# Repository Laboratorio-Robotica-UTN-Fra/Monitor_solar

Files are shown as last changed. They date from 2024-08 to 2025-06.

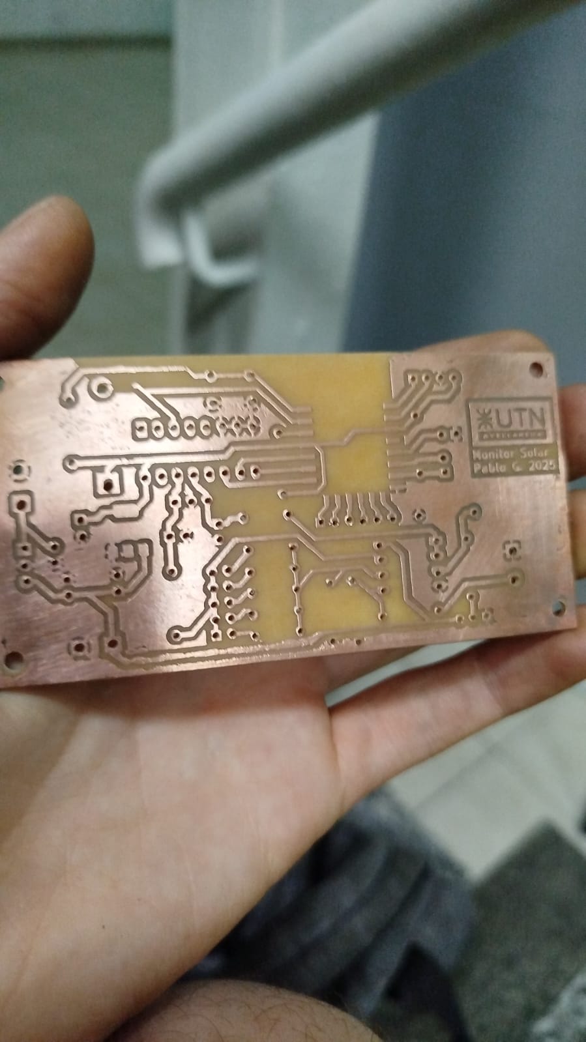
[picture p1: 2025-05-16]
img/1_placa_virgen.jpg

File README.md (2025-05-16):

# Monitor Solar

Proyecto para mostrar los valores de tension y corriente de un sistema solar

## Folder Structure

- `code/` - Archivos de codigo para esp8266.
- `Componentes/` - Documentacion y archivos de simbolos para kicad.
- `img/` - Imagenes del proyecto
- `README.md` - Explicacion del proyecto.

## Getting Started

1. Clone the repository:
    ```bash
    git clone https://github.com/yourusername/Monitor_solar.git
    ```
2. Follow instructions in `docs/` to set up and run the project.

## License

See `LICENSE` for details.

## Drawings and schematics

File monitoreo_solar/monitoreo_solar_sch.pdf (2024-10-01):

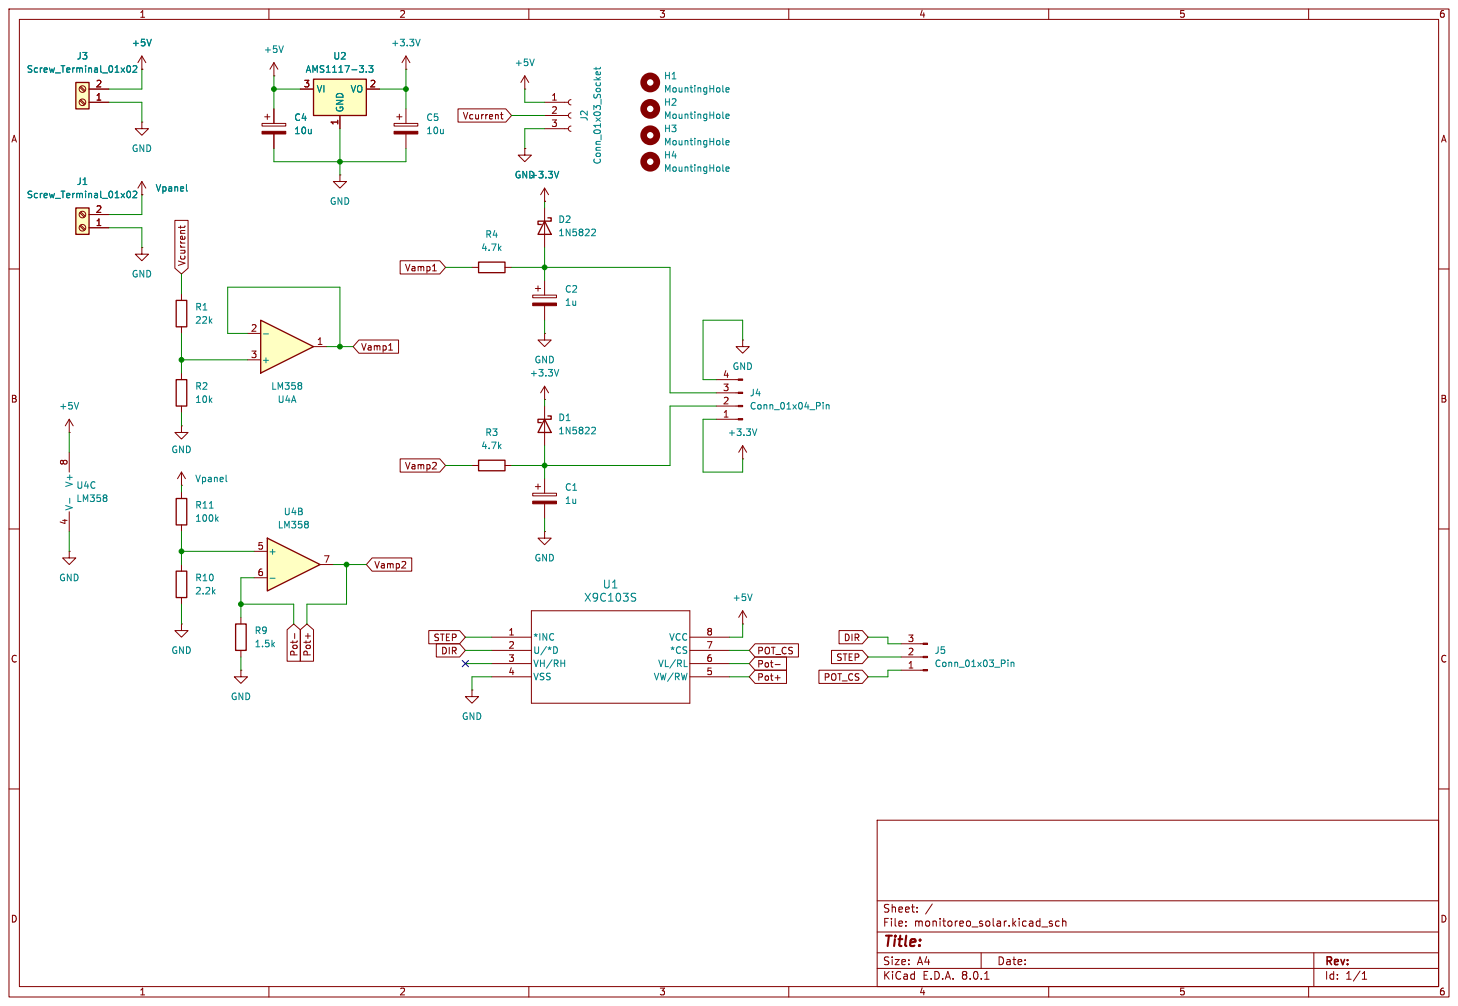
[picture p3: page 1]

Id: 1/1 Title: File: monitoreo_solar.kicad_sch Sheet: / GND

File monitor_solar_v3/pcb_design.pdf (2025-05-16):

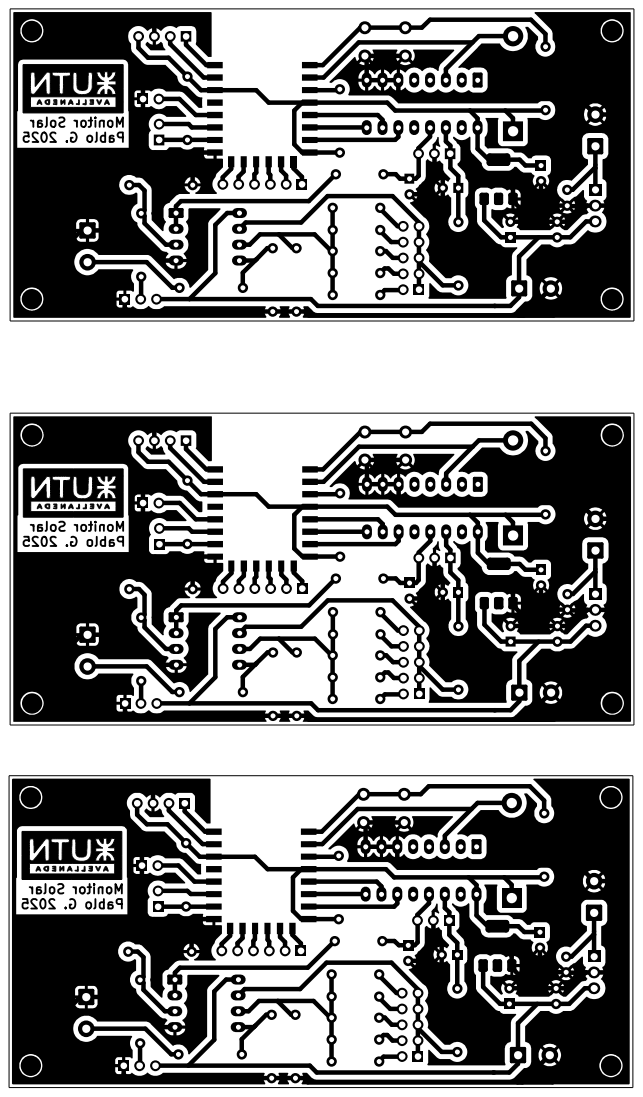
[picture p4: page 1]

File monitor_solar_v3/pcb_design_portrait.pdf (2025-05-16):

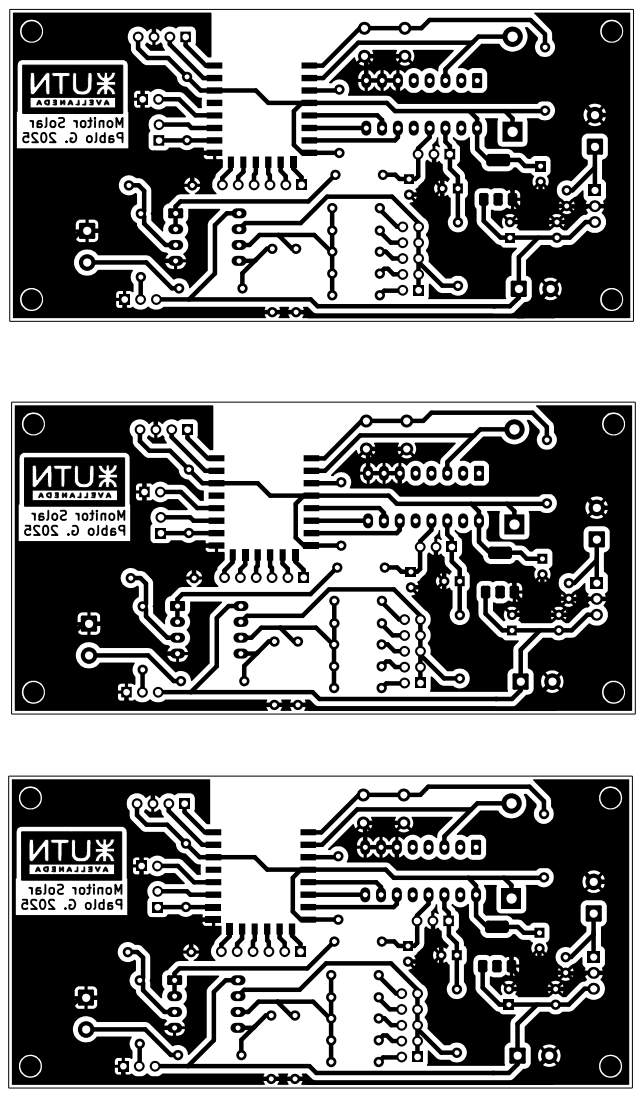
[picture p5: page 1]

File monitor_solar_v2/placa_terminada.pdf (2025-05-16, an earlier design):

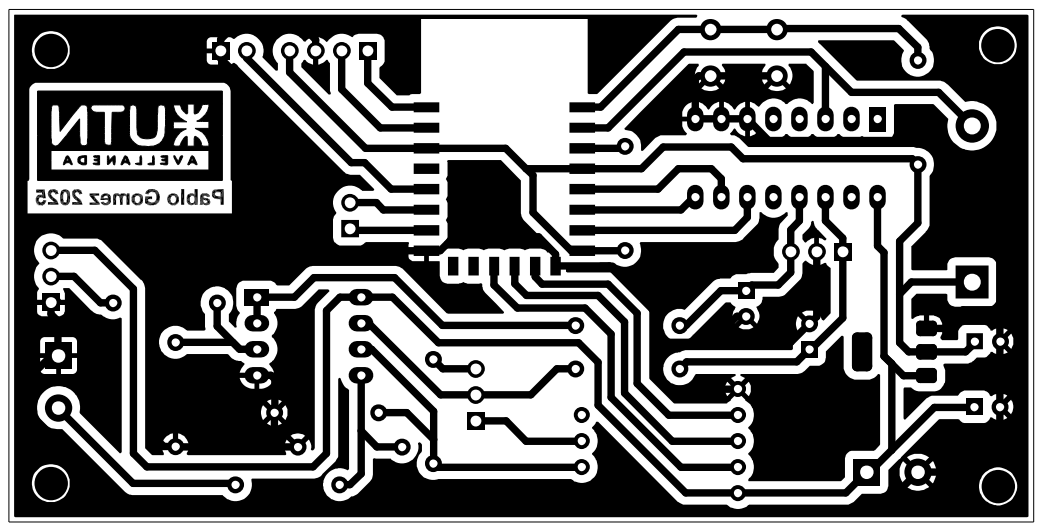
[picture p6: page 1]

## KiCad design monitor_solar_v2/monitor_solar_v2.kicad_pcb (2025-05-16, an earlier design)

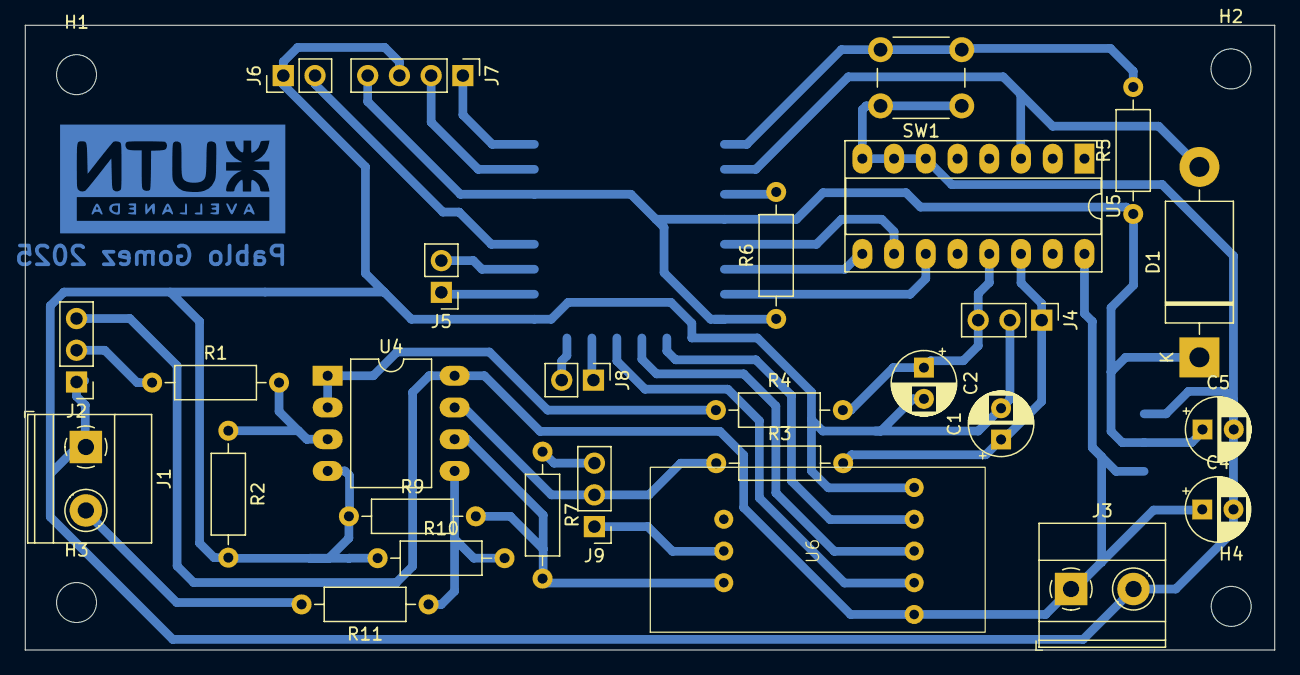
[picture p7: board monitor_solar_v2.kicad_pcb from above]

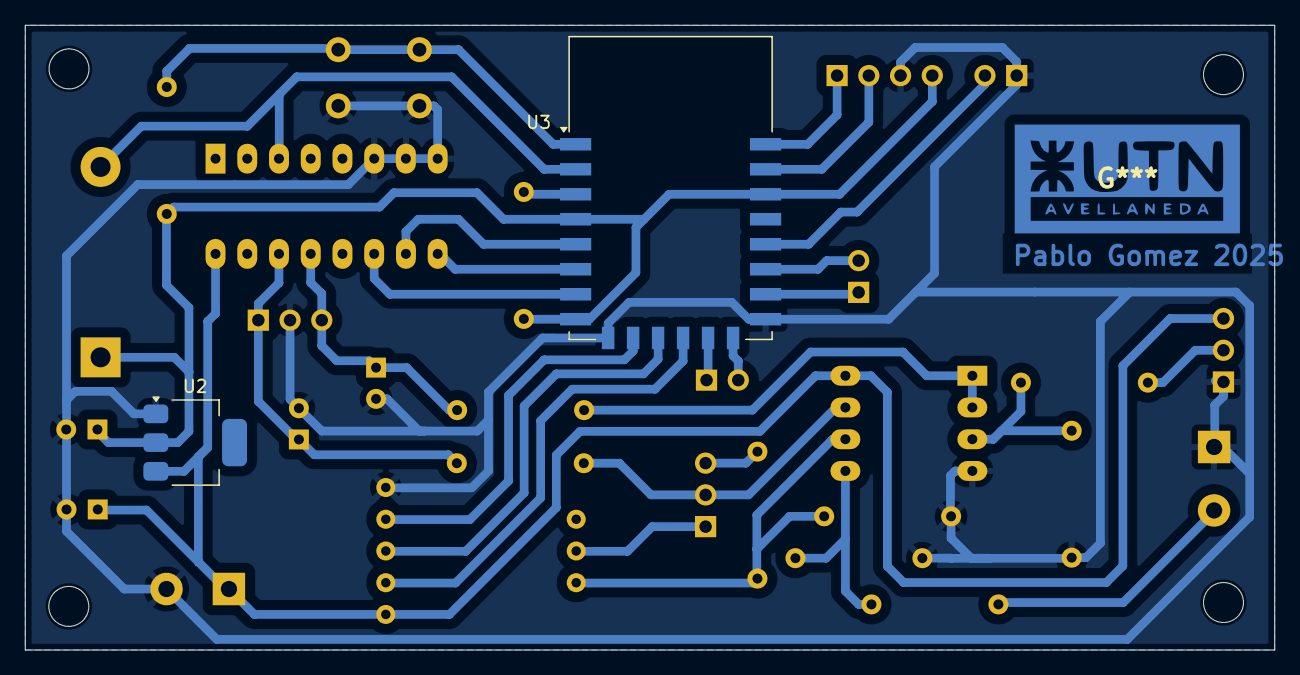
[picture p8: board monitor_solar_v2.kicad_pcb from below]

Board: 2 copper layers, 100.0 x 50.0 mm, 34 parts (2 on the bottom side), 30 nets.

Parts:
C1, C2: 1u; CP_Radial_D5.0mm_P2.50mm
C4, C5: 10u; CP_Radial_D5.0mm_P2.50mm
D1: 1N5822; D_DO-201AD_P15.24mm_Horizontal
H1, H2, H3, H4: MountingHole; MountingHole_3.2mm_M3
J1: Panel; TerminalBlock_Phoenix_MKDS-1,5-2-5.08_1x02_P5.08mm_Horizont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
J2: ACS712; PinHeader_1x03_P2.54mm_Vertical
J3: Reg 5V; TerminalBlock_Phoenix_MKDS-1,5-2_1x02_P5.00mm_Horizontal
J4: AMP_OUT; PinHeader_1x03_P2.54mm_Vertical
J5, J6: JUMPER_PROG; PinHeader_1x02_P2.54mm_Vertical
J7: PROGRAM; PinHeader_1x04_P2.54mm_Vertical
J8: GPIO_2; PinHeader_1x02_P2.54mm_Vertical
J9: Jumper_fixed_r; PinHeader_1x03_P2.54mm_Vertical
R1: 20k; R_Axial_DIN0207_L6.3mm_D2.5mm_P10.16mm_Horizontal
R2, R5, R6: 10k; R_Axial_DIN0207_L6.3mm_D2.5mm_P10.16mm_Horizontal
R3, R4: 4.7k; R_Axial_DIN0207_L6.3mm_D2.5mm_P10.16mm_Horizontal
R7: 3.3k; R_Axial_DIN0207_L6.3mm_D2.5mm_P10.16mm_Horizontal
R9: 1.5k; R_Axial_DIN0207_L6.3mm_D2.5mm_P10.16mm_Horizontal
R10: 2.2k; R_Axial_DIN0207_L6.3mm_D2.5mm_P10.16mm_Horizontal
R11: 100k; R_Axial_DIN0207_L6.3mm_D2.5mm_P10.16mm_Horizontal
SW1: SW_Push; SW_PUSH_6mm
U2: AMS1117-3.3; SOT-223-3_TabPin2
U3: ESP-12F; ESP-12E
U4: LM358; DIP-8_W10.16mm_LongPads
U5: 4051; DIP-16_W7.62mm_Socket_LongPads
U6: X9C103S

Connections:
+3.3V: C5.1, D1.1 (K), J7.4, R5.1, R6.1, U2.2 (VO), U3.4 (GPIO16), U3.8 (VCC), U3.20 (GPIO5)
+5V: C4.1, J2.3, J3.1, U2.3 (VI), U4.8 (V+), U5.16 (VDD), U6.8 (VCC)
ADC_IN: D1.2 (A), U3.2 (ADC), U5.3 (X)
DIR: U3.10 (MISO), U6.2 (U/*D)
GND: C1.2, C2.2, C4.2, C5.2, J1.1, J2.1, J3.2, J4.2, J6.1, J7.3, R2.2, R9.1, R10.1, SW1.1, U2.1 (GND), U3.9 (CS0), U3.15 (GND), U4.4 (V-), U5.6 (Inh), U5.7 (VEE), U5.8 (VSS), U6.4 (VSS)
GPIO2: J5.2, U3.17 (GPIO2)
GPIO15: J5.1, U3.16 (GPIO15)
MUX_A: U3.7 (GPIO13), U5.11 (A)
MUX_B: U3.5 (GPIO14), U5.10 (B)
MUX_C: U3.6 (GPIO12), U5.9 (C)
unnamed: J6.2, U3.18 (GPIO0)
unnamed: J8.1, U3.13 (MOSI)
unnamed: J8.2, U3.14 (SCLK)
unnamed: J9.2, R3.1, U4.7
unnamed: J9.3, R7.1
unnamed: R6.2, U3.3 (EN)
unnamed: R5.2, SW1.2, U3.1 (~RST)
unnamed: R1.2, R2.1, U4.3 (+)
unnamed: R4.1, U4.1, U4.2 (-)
unnamed: R10.2, R11.1, U4.5 (+)
POT_CS: U3.12 (GPIO10), U6.7 (*CS)
Pot+: J9.1, U6.5 (VW/RW)
Pot-: R7.2, R9.2, U4.6 (-), U6.6 (VL/RL)
RX: J7.2, U3.21 (GPIO3/RXD)
STEP: U3.11 (GPIO9), U6.1 (*INC)
TX: J7.1, U3.22 (GPIO1/TXD)
Vamp1: C2.1, J4.3, R4.2, U5.13 (X0)
Vamp2: C1.1, J4.1, R3.2, U5.14 (X1)
Vcurrent: J2.2, R1.1
Vpanel: J1.2, R11.2

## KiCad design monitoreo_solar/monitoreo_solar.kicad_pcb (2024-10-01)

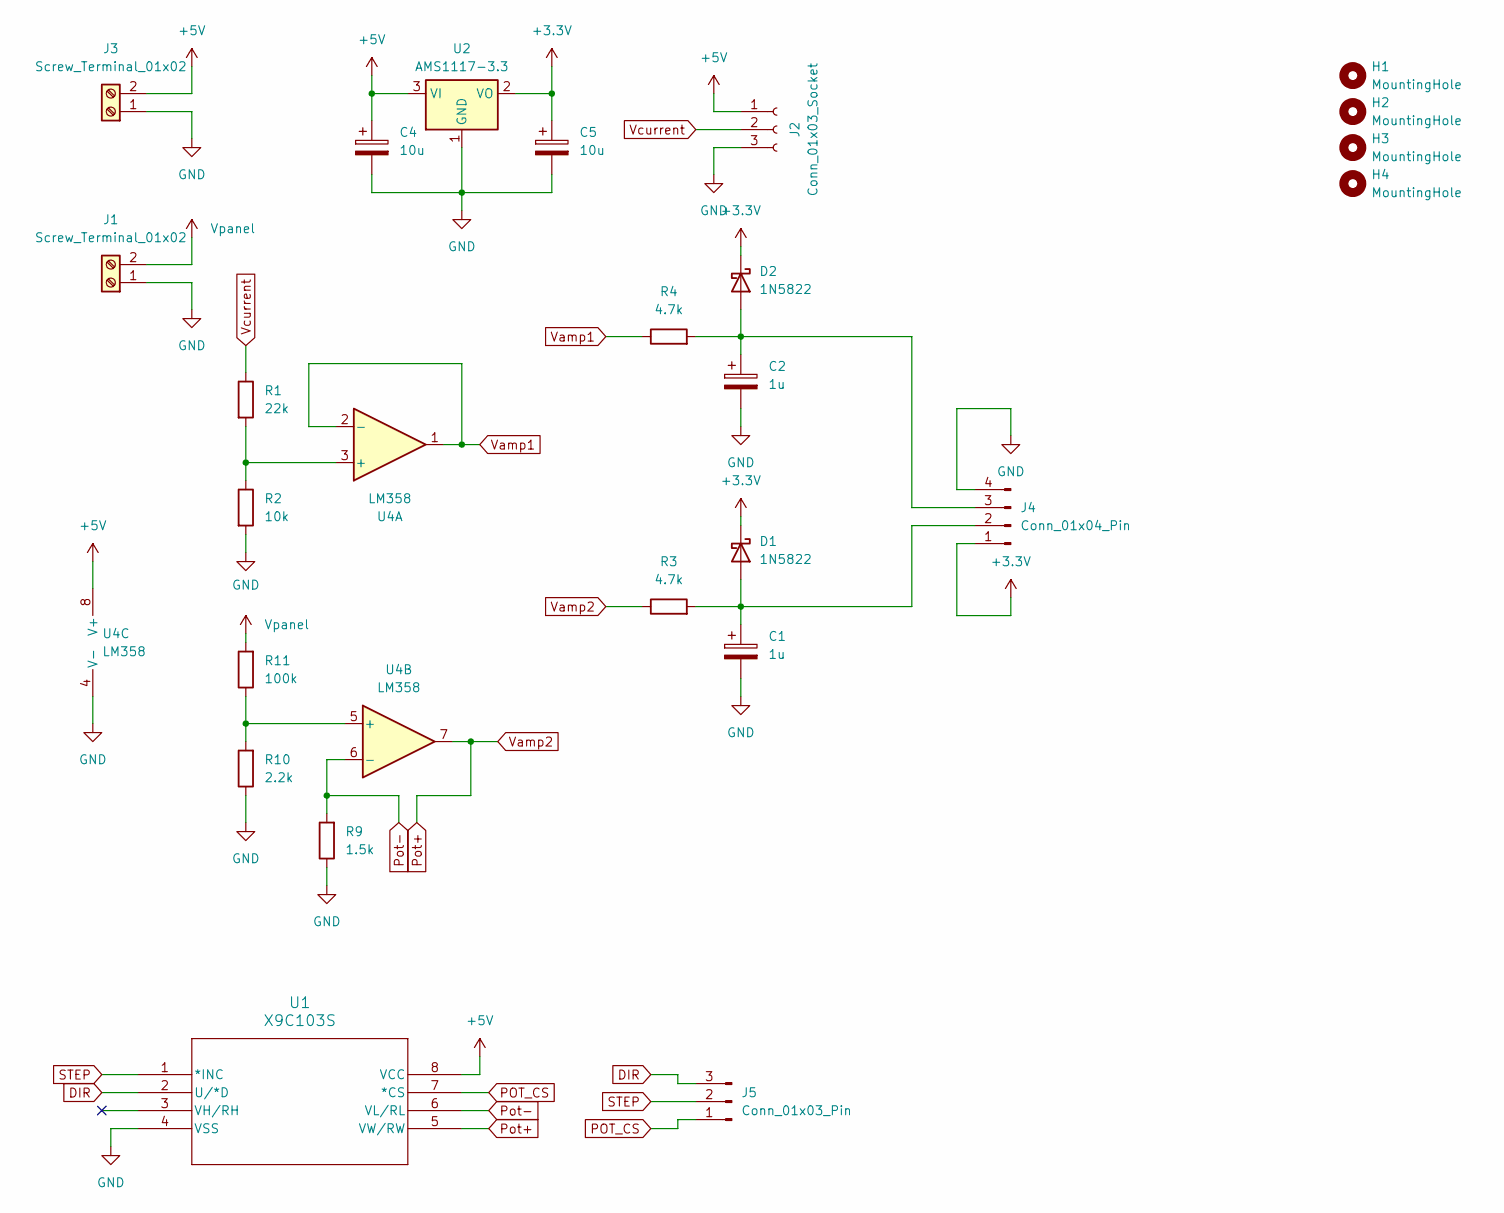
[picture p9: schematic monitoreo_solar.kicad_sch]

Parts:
C1, C2: 1u; CP_Radial_D5.0mm_P2.50mm
C4, C5: 10u; CP_Radial_D5.0mm_P2.50mm
D1, D2: 1N5822; D_DO-201AD_P15.24mm_Horizontal
H1, H2, H3, H4: MountingHole; MountingHole_3.2mm_M3
J1, J3: Screw_Terminal_01x02; TerminalBlock_Phoenix_MKDS-1,5-2_1x02_P5.00mm_Horizontal
J2: Conn_01x03_Socket; PinHeader_1x03_P2.54mm_Vertical
J4: Conn_01x04_Pin; PinHeader_1x04_P2.54mm_Vertical
J5: Conn_01x03_Pin; PinHeader_1x03_P2.54mm_Vertical
R1: 22k; R_Axial_DIN0207_L6.3mm_D2.5mm_P10.16mm_Horizontal
R2: 10k; R_Axial_DIN0207_L6.3mm_D2.5mm_P10.16mm_Horizontal
R3, R4: 4.7k; R_Axial_DIN0207_L6.3mm_D2.5mm_P10.16mm_Horizontal
R9: 1.5k; R_Axial_DIN0207_L6.3mm_D2.5mm_P10.16mm_Horizontal
R10: 2.2k; R_Axial_DIN0207_L6.3mm_D2.5mm_P10.16mm_Horizontal
R11: 100k; R_Axial_DIN0207_L6.3mm_D2.5mm_P10.16mm_Horizontal
U1: X9C103S; SOIC8_3P9116X4P9022_INR
U2: AMS1117-3.3; TO-220-3_Vertical
U4: LM358; DIP-8_W10.16mm_LongPads

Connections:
+3.3V: C5.1, D1.1 (K), D2.1 (K), J4.1, U2.2 (VO)
+5V: C4.1, J2.1, J3.2, U1.8 (VCC), U2.3 (VI), U4.8 (V+)
DIR: J5.3, U1.2 (U/*D)
GND: C1.2, C2.2, C4.2, C5.2, J1.1, J2.3, J3.1, J4.4, R2.2, R9.1, R10.1, U1.4 (VSS), U2.1 (GND), U4.4 (V-)
unnamed: C1.1, D1.2 (A), J4.2, R3.2
unnamed: C2.1, D2.2 (A), J4.3, R4.2
unnamed: R1.2, R2.1, U4.3 (+)
unnamed: R10.2, R11.1, U4.5 (+)
POT_CS: J5.1, U1.7 (*CS)
Pot+: R3.1, U1.5 (VW/RW), U4.7
Pot-: R9.2, U1.6 (VL/RL), U4.6 (-)
STEP: J5.2, U1.1 (*INC)
Vamp1: R4.1, U4.1, U4.2 (-)
Vcurrent: J2.2, R1.1
Vpanel: J1.2, R11.2

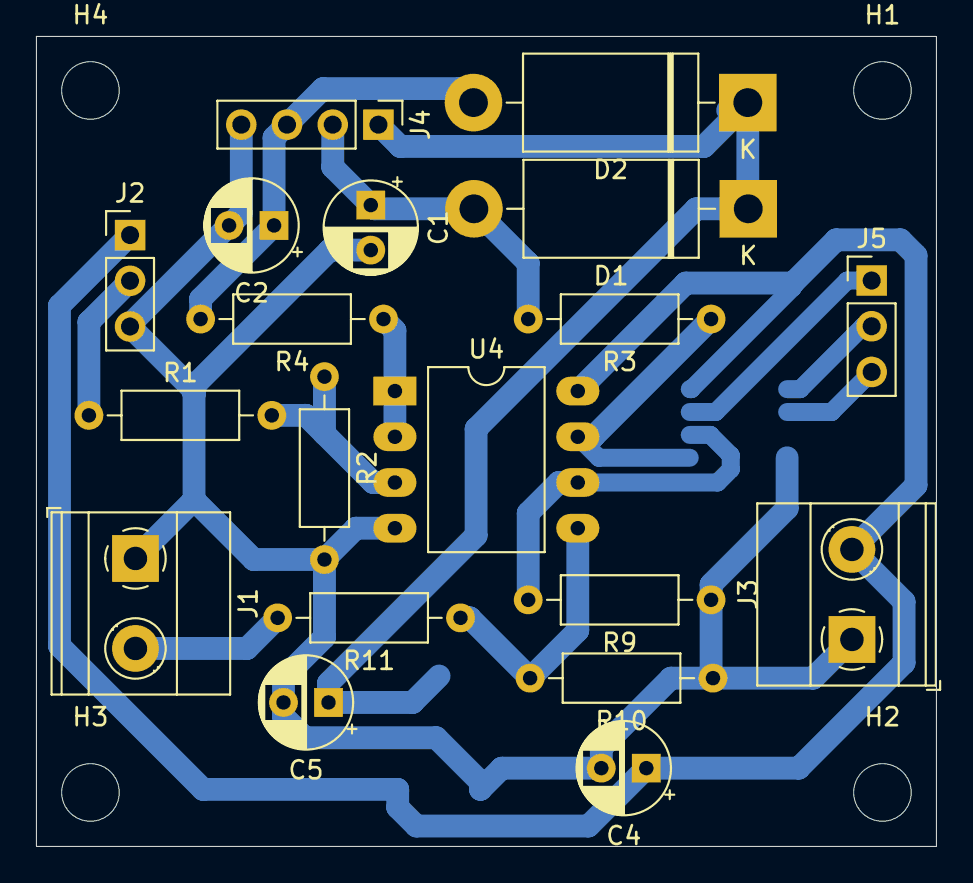
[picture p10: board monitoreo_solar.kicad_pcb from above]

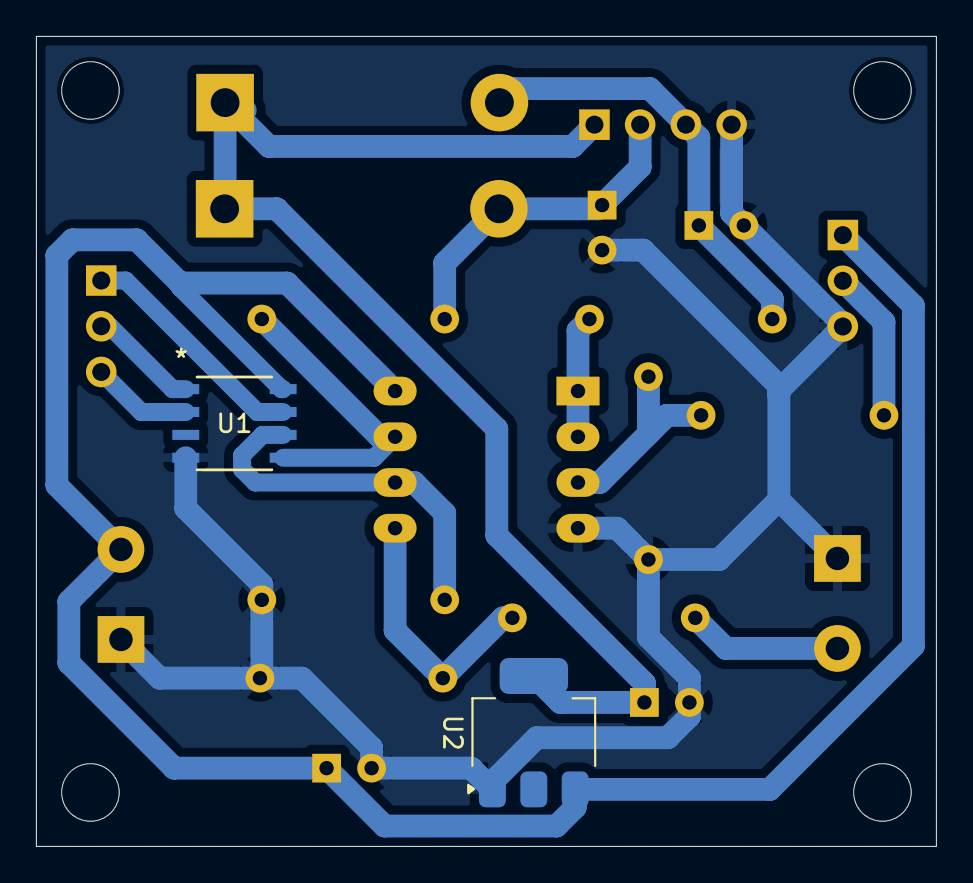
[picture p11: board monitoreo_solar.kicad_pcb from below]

Board: 2 copper layers, 50.0 x 45.0 mm, 25 parts (2 on the bottom side), 15 nets.

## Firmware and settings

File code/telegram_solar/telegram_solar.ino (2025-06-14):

#include <ESP8266WiFi.h>
#include <WiFiClientSecure.h>
#include <UniversalTelegramBot.h>
#include "monitor_functions.h"
#include "telegram_content.h"


#define GPIO_LED    2
#define GPIO_LED_ON 0
#define SPREADSHEET_ON 0

unsigned long tiempoInicio;
unsigned long ultimaVezMensaje = 0;
unsigned long ultimaVezGsheet = 0;

unsigned long intervaloMensajes = 500;
unsigned long intervaloGsheet = 10000;
int n_new_messages;

void setup()
{
    Serial.begin(115200);
    tiempoInicio = millis();
    Serial.println("Start Device");
    #if GPIO_LED_ON
    pinMode(GPIO_LED, OUTPUT);
    #endif
    solar_gpio_init();
    Serial.println("Finish GPIO");
    conectarWiFi();
    
    
    select_sensor(VOLTAGE);
    float v_adc_value = get_voltage_value(3300);
    Serial.print("El valor de tension actualmente es: ");
    Serial.println(v_adc_value);
    Serial.print("Voltaje de entrada: ");
    Serial.println(analogRead(A0) * ADC_BITS2VOLTS);
    delay(500);

    select_sensor(CURRENT);
    float i_adc_value = get_current_value();
    Serial.print("El valor de corriente actualmente es: ");
    Serial.println(i_adc_value);
    Serial.print("Voltaje de entrada: ");
    Serial.println(analogRead(A0) * ADC_BITS2VOLTS);

    ultimaVezGsheet = millis();
}


void loop()
{
    if (WiFi.status() == WL_CONNECTED)
    {
        // Parpadeo cuando hay conexión
        #if SPREADSHEET_ON
        if (millis() - ultimaVezGsheet > intervaloGsheet) {
            Serial.println("Guardar data en gsheet");
            PanelData panel_data = get_panel_data(ultimaVezGsheet);
            sendDataToGoogleSheets(panel_data);
            ultimaVezGsheet = millis();

        }
        #endif
        if (millis() - ultimaVezMensaje > intervaloMensajes)
        {
            #if GPIO_LED_ON
            digitalWrite(GPIO_LED, HIGH);
            #endif
            n_new_messages = bot.getUpdates(bot.last_message_received + 1);
            while(n_new_messages > 0) {
                manejarMensajesNuevos(n_new_messages);
                n_new_messages = bot.getUpdates(bot.last_message_received + 1);
            }
            ultimaVezMensaje = millis();
        }
    }
    else
    {
        Serial.println("Error desconexion de wifi");
        // Si se pierde la conexión, reconectar y mantener el LED fijo
        #if GPIO_LED_ON
        digitalWrite(GPIO_LED, LOW);
        #endif
        conectarWiFi();
    }

}

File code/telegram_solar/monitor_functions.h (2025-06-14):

#ifndef __MONITOR_FUNCTIONS__
#define __MONITOR_FUNCTIONS__

#include "Arduino.h"
#include <NTPClient.h>
#include <WiFiUdp.h>

#define GPIO_MUX_A  13
#define GPIO_MUX_B  14
#define GPIO_MUX_C  12

#define GPIO_RELAY_1  10
#define GPIO_RELAY_2  2

#define ADC_RESOLUTION 1024
#define ADC_VREF 1.0f
#define ADC_BITS2VOLTS ((float) (ADC_VREF / ADC_RESOLUTION))


// 2.2 * (1 + 3.3 / 1.5) / 102.2 = 0.068845 => ^-1 = 14.517
#define ADC_V_GAIN 100680.0 / 680
#define PANEL_V_OFFSET 0.6f
// Resistencias = ((33k + 20k) / 33k)
// Inversa de la pendiente sensor ACS712
// 52k // 100k => 0.342 ~ 0.35
// 0A -> 2.52v -> 0.88v     | 0 v
// 30A -> 0.55v -> 0.19v    | 0.69 v
#define ACS712_OFFSET_COUNTS 934
#define ACS712_SENSITIVITY 42.47f 


WiFiUDP ntpUDP;
NTPClient timeClient(ntpUDP, "pool.ntp.org", -3 * 3600, 60000);

enum sensor_type{
    VOLTAGE,
    CURRENT
};

void select_sensor(enum sensor_type tipo);
struct PanelData {
    float voltage;
    float current;
    float power;
    float energy;
    String date_time;
};

void solar_gpio_init(void) {
    pinMode(GPIO_MUX_A, OUTPUT);
    pinMode(GPIO_MUX_B, OUTPUT);
    pinMode(GPIO_MUX_C, OUTPUT);
    select_sensor(VOLTAGE);
    
    pinMode(GPIO_RELAY_1, OUTPUT);
    pinMode(GPIO_RELAY_2, OUTPUT);
    digitalWrite(GPIO_RELAY_1, HIGH);
    digitalWrite(GPIO_RELAY_2, HIGH);
}

float get_voltage_value(int r1_value) {
    float gain =  ADC_V_GAIN / (1 + r1_value / 1500.0);
    return gain * analogRead(A0) * ADC_BITS2VOLTS - PANEL_V_OFFSET;
}

float get_current_value() {
    float adc_i_volts =  ACS712_SENSITIVITY * (ACS712_OFFSET_COUNTS - analogRead(A0)) * ADC_BITS2VOLTS;
    return adc_i_volts; // - 0.878
}


void select_sensor(enum sensor_type tipo) {
    switch (tipo) {
        case VOLTAGE:
            digitalWrite(GPIO_MUX_A, LOW);
            digitalWrite(GPIO_MUX_B, HIGH);
            digitalWrite(GPIO_MUX_C, LOW);
            break;
        case CURRENT:
            digitalWrite(GPIO_MUX_A, HIGH);
            digitalWrite(GPIO_MUX_B, HIGH);
            digitalWrite(GPIO_MUX_C, LOW);
            break;
    }
    delay(50);
}

void print_panel_data(PanelData panel_data) {
    Serial.println("Voltage: " + String(panel_data.voltage) + "V");
    Serial.println("Current: " + String(panel_data.current) + "A");
    Serial.println("Power: " + String(panel_data.power) + "W");
    Serial.println("Energy: " + String(panel_data.energy) + "kWh");
    Serial.println("Date/Time: " + panel_data.date_time);
}

PanelData get_panel_data(unsigned long last_reading_time) {
    PanelData panel_data;
    panel_data.voltage = get_voltage_value(3300);
    panel_data.current = get_current_value();
    panel_data.power = panel_data.voltage * panel_data.current;
    panel_data.energy += panel_data.power * (millis() - last_reading_time) / 3600000.0; // kWh
    timeClient.update();
    panel_data.date_time = timeClient.getFormattedTime();
    
    print_panel_data(panel_data);

    return panel_data;
}

#endif

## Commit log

2024-08-14 feat: add schematic and notebook with first values
    [monitoreo_solar.kicad_pcb, monitoreo_solar.kicad_sch, mux_variable_resistance.kicad_pcb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]
2024-08-15 first pcb design
    [monitoreo_solar-B_Cu.gbr, monitoreo_solar-B_Mask.gbr, monitoreo_solar-B_Paste.gbr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]
2024-10-01 feat: v2 pcb con board potenciometro a medida
    [monitor_solar_v2-B_Cu.gbr, monitor_solar_v2-B_Mask.gbr, monitor_solar_v2-B_Paste.gbr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]
2024-10-02 Test Flatcam
    Prueba para utilizar flatcam a partir de la pcb v2
    [monitor_solar_v2-B_Cu.gbr, monitor_solar_v2-B_Mask.gbr, monitor_solar_v2-B_Paste.gbr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]
2025-03-07 Cambios menores
    [monitor_solar_v2.kicad_pcb, monitor_solar_v2.kicad_sch]
2025-03-14 Adding ESP-12 and new pcb
    [monitor_solar_v2.kicad_pcb, monitor_solar_v2.kicad_sch, monitor_solar_v2_0.kicad_pcb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]
2025-03-18 PCB esp12 v1.0
    [monitor_solar_v2.kicad_pcb, monitor_solar_v2.kicad_sch]
2025-03-21 codigo v1: pruebas en telegram
    [monitor_solar_v2.kicad_pcb, monitor_solar_v2.kicad_sch]
2025-03-22 MUX, OpAmp and Relay tested
2025-03-26 PCB v3
    [monitor_solar_v3.kicad_pcb, monitor_solar_v3.kicad_sch]
2025-03-27 PCB V3 finished
    [monitor_solar_v3.kicad_pcb, monitor_solar_v3.kicad_sch]
2025-04-04 Add led for power status
    [monitor_solar_v3.kicad_pcb, monitor_solar_v3.kicad_sch]
2025-04-04 Cambios en el codigo para telegram y ajuste de resistencias del pcb
2025-04-21 Cambios en la sensibilidad de los canales. Modificar valores de resistencias en esquematico
    [monitor_solar_v3.kicad_sch]
